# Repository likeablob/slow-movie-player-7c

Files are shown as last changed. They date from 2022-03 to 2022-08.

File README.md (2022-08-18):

<p align="center">
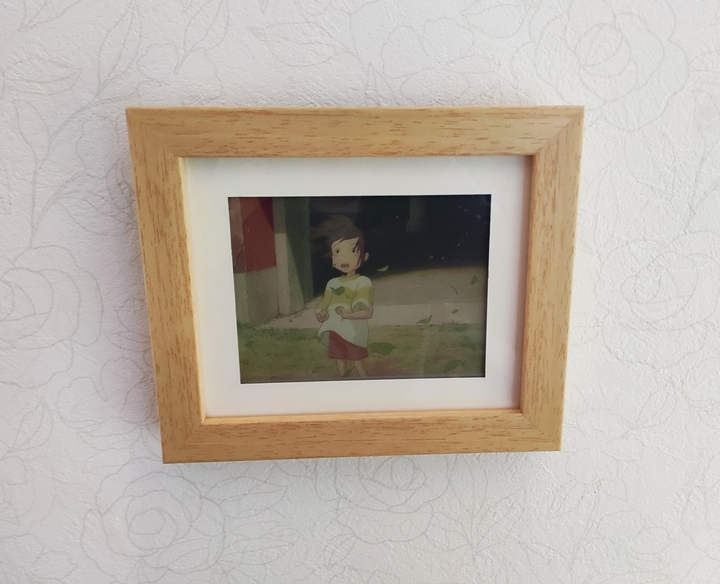
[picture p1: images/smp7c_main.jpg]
  
  <p align="center">
  <small>From "Spirited Away (2001)" © 2001 Studio Ghibli・NDDTM.</small>
  </p>
</p>

https://user-images.githubusercontent.com/46628917/185350349-dca5a5df-3bee-4c23-829b-23d41562c1f2.mp4

# slow-movie-player-7c



Yet another "Slow Movie Player" implementation with 7-color E-Paper module and ESP32.

Features:

- 7-color E-Paper
- microSD (MMC_SD) as the main storage
- Power management by the ESP32 ULP coprocessor
- Battery operated (12 uA @ Deep Sleep. Runs 1.2 years on a 2000 mAh battery.)

## Table of Contents

- [Background](#background)
- [Install](#install)
- [Usage](#usage)
- [Maintainers](#maintainers)
- [Contributing](#contributing)
- [License](#license)

## Background

A few years later from my previous EPD project [SHIHEN](https://github.com/likeablob/shihen), while being impressed on "Slow Movie" and forks ([[1]](https://hackaday.io/project/179122-slow-ish-movie-player), [[2]](https://github.com/TomWhitwell/SlowMovie)), I was wondering it would be fun if I could also have something bigger and more eye-catching than SHIHEN. One day I found a multi-color E-Paper module available and immediately made an impulse buy. At that time, in [Endless Endless Eight](https://github.com/likeablob/endless-endless-eight/) I had just started learning how powerful ESP32 ULP co-processor is, especially for battery-powered devices. So I decided to make a yet another variant of slow movie player by combining the two components.

The 7-color EPD module has notoriously long refresh time (>= 30 sec), however by delegating BUSY signal handlings to the ULP co-processor, the ESP32 module itself can be stay in Deep Sleep at most of the time.

Given the ESP32 module in the Deep Sleep mode only draws a dozen uA (Actually `12 uA` measured = `6 uA for the module` + `6 uA for peripherals`.), [theoretically the device can survive over a year](https://blc.vercel.app/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) under a 2000 mAh rated battery and 2 hours of wake interval.

## Install

### BOM

_WIP_

- ESP32 (ESP-WROOM-32)
- Waveshare ACeP 7-Color E-Paper Display Module (600x448 5.65inch)
- SMD microSD slot
- microSD card
- M2\*5 screws \* 4
- AAA batteries \* 3

### Wire components

See [./kicad](./kicad).

### Print spacers

See [./openscad](./openscad).

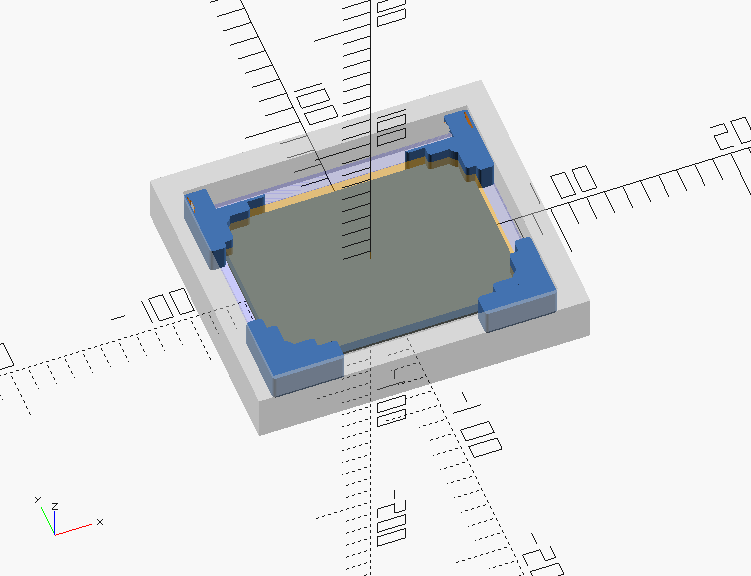
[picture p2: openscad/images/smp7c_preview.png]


### Build firmware

```sh
$ pio run || pio run # The very 1st run may fail due to ulptool-pio
$ pio run -t upload
```

## Usage

### Prepare video file

Your video file must get converted to a special format before being placed on the microSD.
Simply put `1. Dump video frames to a bunch of PNG images.` `2. Apply palette to the images.` `3. Concat the images into a single file.`

You have several options as follows. After obtaining `index.bin` and `images.bin`, place them onto the root of your FAT32-formatted microSD.

#### Option A: With Docker

```sh
$ cd converter
$ cp path/to/your_vid_file .
$ docker-compose run --rm converter your_vid_file
```

#### Option B: With .sh

- Note that you have to install ffmpeg, ImageMagick, node(v16) beforehand.

```sh
$ cd converter
$ ./convert.sh path/to/your_vid_file
```

#### Option C: By your hand

1. Dump video frames into .png files.

```sh
$ cd converter
$ mkdir -p vid

# -r 1/2 == 0.5 FPS
$ ffmpeg -i path/to/your_vid_file -r 1/2 -vf scale=-1:448,crop=600:448 vid/vid_%06d.png
```

As you may have noticed, you can use any kind of image sources here not only usual video files.

2. Reduce colors with the following 7-color palette.  
   

```sh
$ mogrify -monitor -dither FloydSteinberg -remap epaper_7c_palette.png vid/*
```

3. Generate `index.bin` and `images.bin`.

```sh
$ npm ci
$ node generate-index-bin.js vid/
```

### How it works

_WIP_

## Maintainers

[@likeablob](https://github.com/likeablob)

## Contributing

PRs accepted.

Small note: If editing the README, please conform to the [standard-readme](https://github.com/RichardLitt/standard-readme) specification.

## License

MIT

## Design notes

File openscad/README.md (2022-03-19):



# SMP7C parts

```sh
# Ensure you have submodules
$ git submodule update --init

# Convert *.scad to *.stl
$ make stls

# Generate thumbnails
$ make images
```

All the `*.stl` files are available under [`./stl`](./stl).

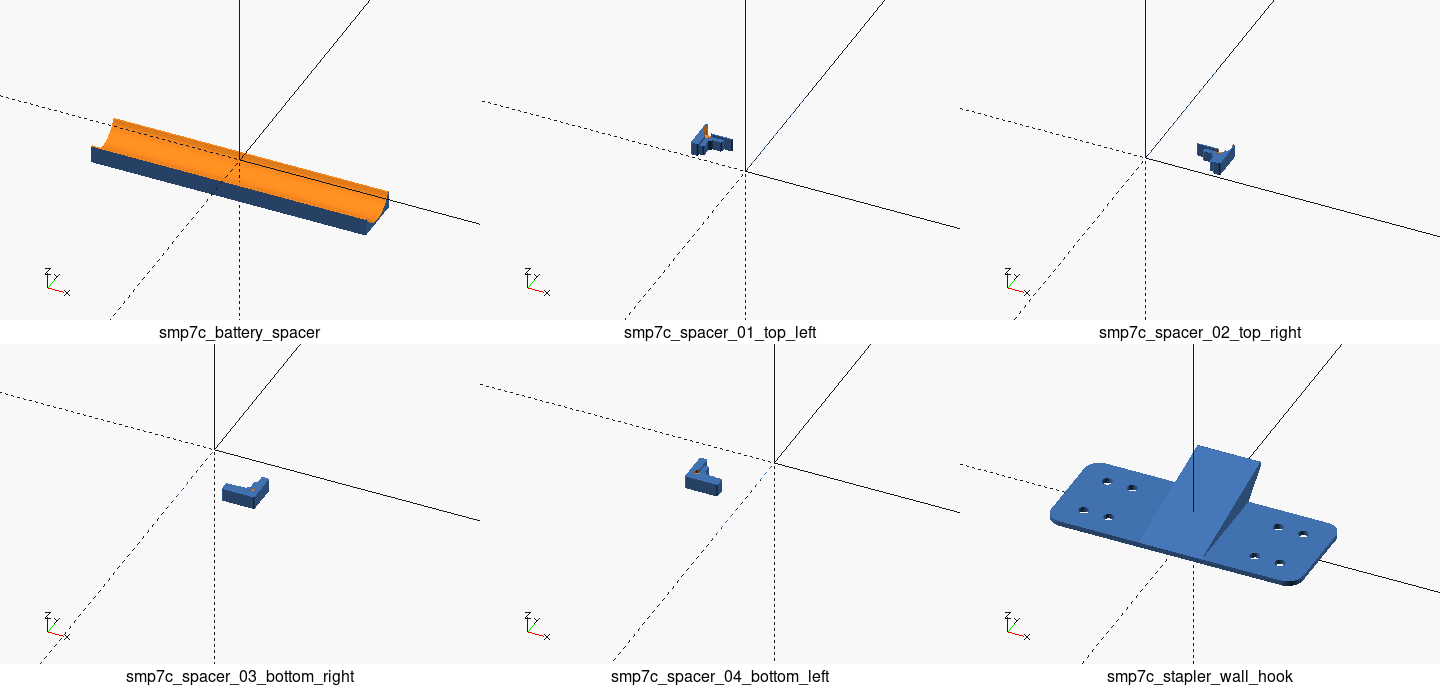
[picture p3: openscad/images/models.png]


## Recommended print configuration

- PLA
- Layer: 0.2 mm

## Parameters

See [`_preview_picture_frame_parameters.scad`](./_preview_picture_frame_parameters.scad) for the details.

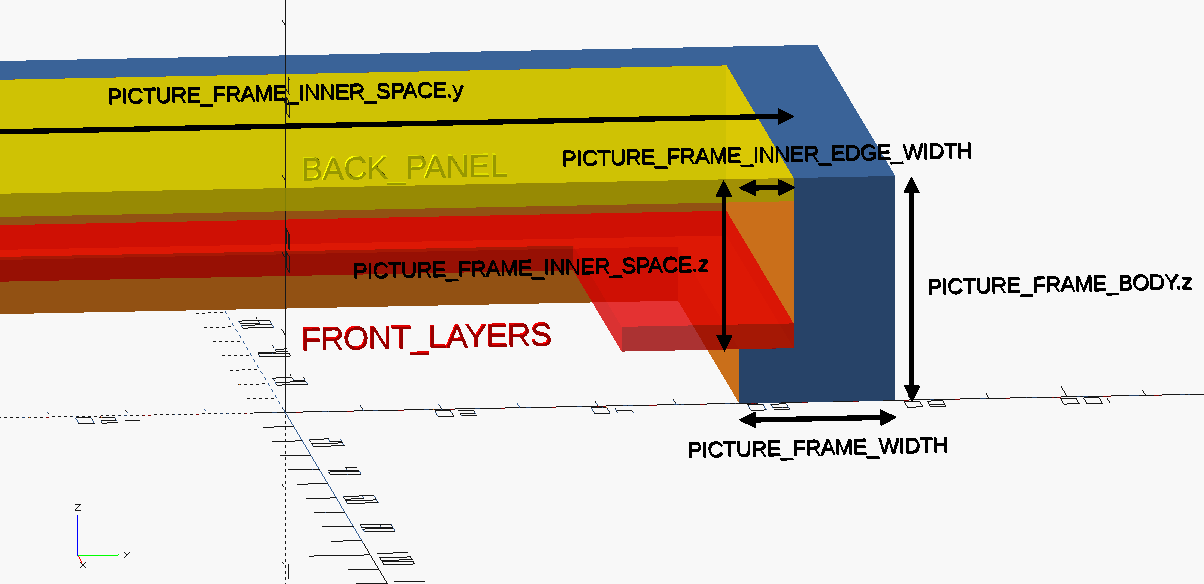
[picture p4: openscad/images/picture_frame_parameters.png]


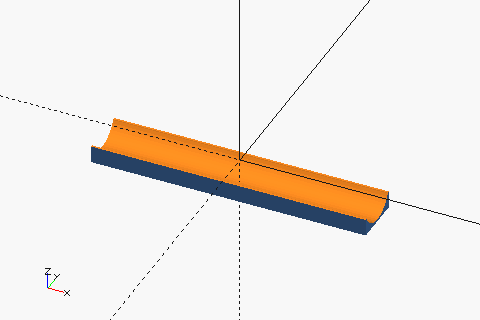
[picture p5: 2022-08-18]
openscad/images/smp7c_battery_spacer.png

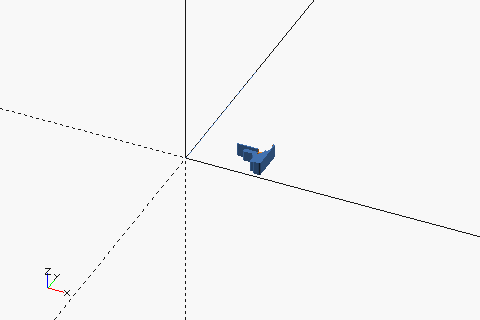
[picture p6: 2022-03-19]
openscad/images/smp7c_spacer_02_top_right.png

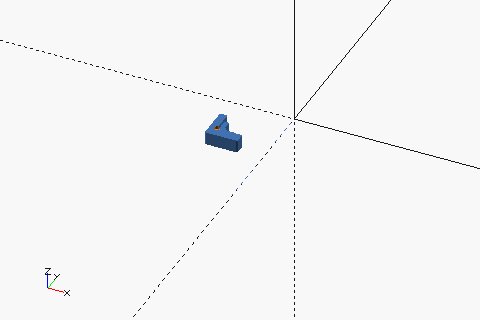
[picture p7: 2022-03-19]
openscad/images/smp7c_spacer_04_bottom_left.png

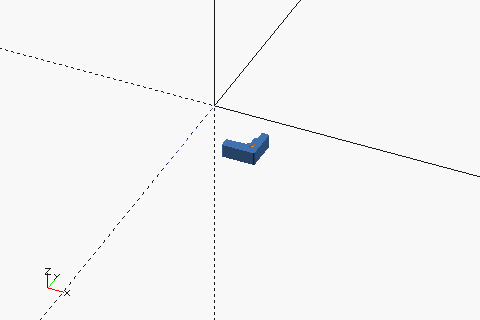
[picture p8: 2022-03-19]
openscad/images/smp7c_spacer_03_bottom_right.png

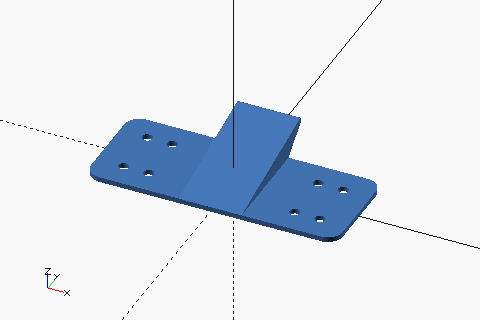
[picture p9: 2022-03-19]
openscad/images/smp7c_stapler_wall_hook.png

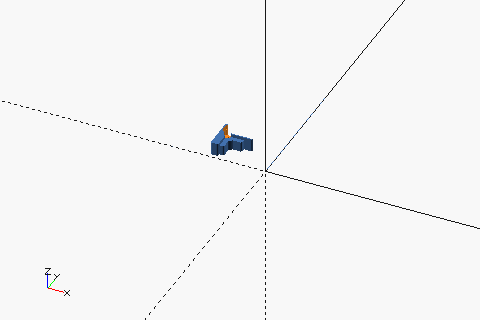
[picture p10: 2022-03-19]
openscad/images/smp7c_spacer_01_top_left.png

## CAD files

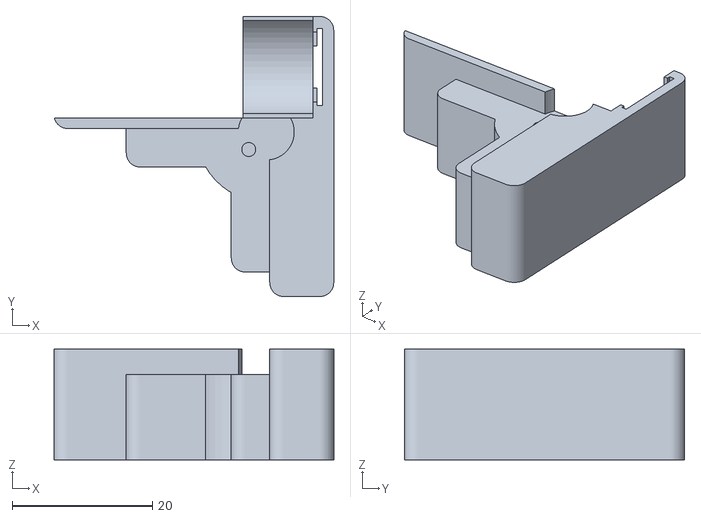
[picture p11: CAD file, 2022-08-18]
openscad/stl/smp7c_spacer_02_top_right.stl
39.9 x 40.0 x 15.8

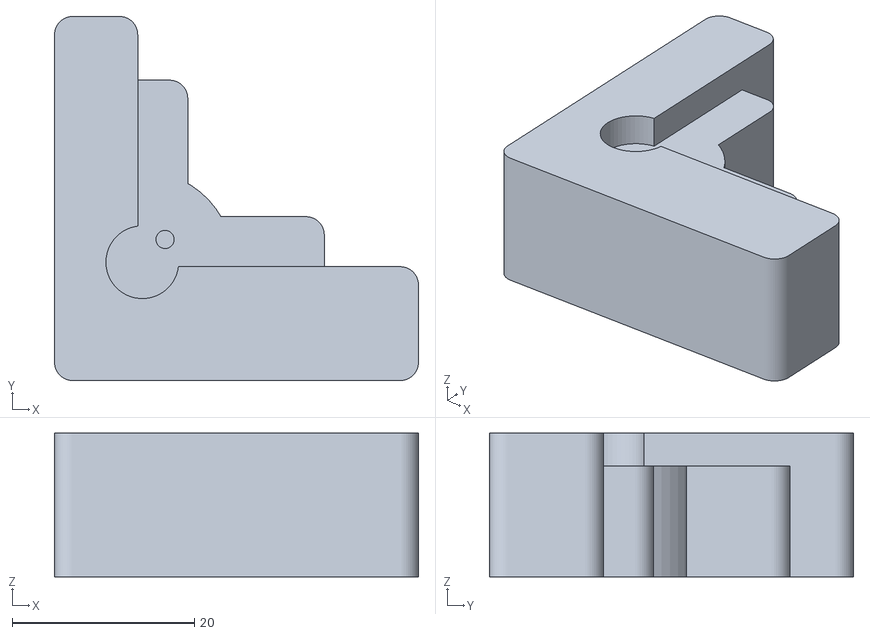
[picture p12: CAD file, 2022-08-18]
openscad/stl/smp7c_spacer_04_bottom_left.stl
40.0 x 40.0 x 15.8

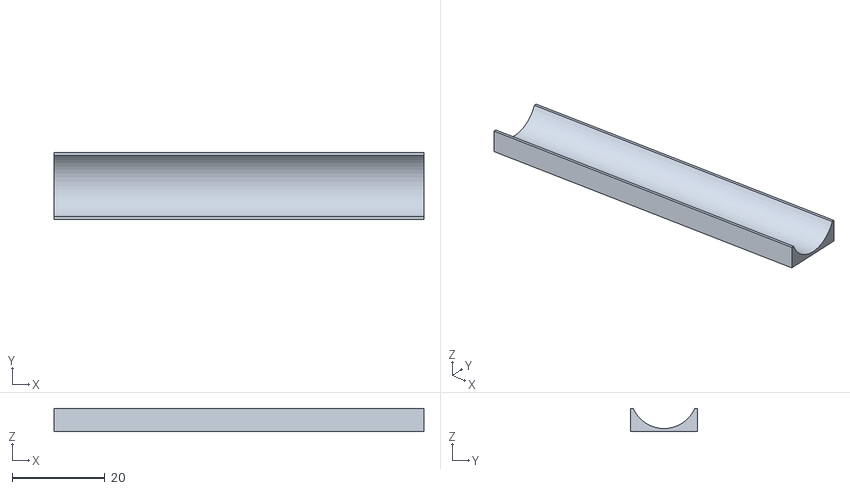
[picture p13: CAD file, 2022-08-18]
openscad/stl/smp7c_battery_spacer.stl
80.0 x 14.5 x 5.00

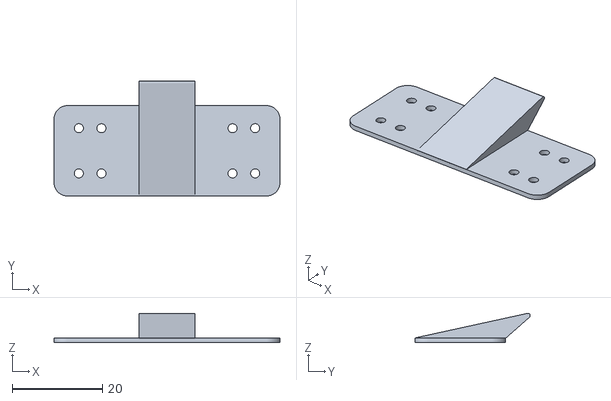
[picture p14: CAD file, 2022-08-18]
openscad/stl/smp7c_stapler_wall_hook.stl
50.0 x 25.5 x 6.50

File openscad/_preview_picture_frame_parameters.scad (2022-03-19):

include <modules/epd_565in_acep.scad>
include <modules/picture_frame.scad>
include <modules/smp7c_spacer.scad>
include <modules/annotation.scad>

$fn=50;

module cut_half_yz() {
  intersection(){
    children();

    translate([-1000/2, 0, 0])
    cube(size=[1000, 1000, 1000], center=true);
  }
}

// Models
cut_half_yz()
picture_frame_body();

translate([0.01, 0, 0])
color("red", 0.8)
cut_half_yz()
picture_frame_front_layers();

translate([0.02, 0, 0])
color("yellow", 0.8)
cut_half_yz()
picture_frame_back_panel();

// Annotations
// on YZ plane
rotate([90, 0, 90]){
  color("black")
  translate([PICTURE_FRAME_BODY.y/2 - PICTURE_FRAME_WIDTH/2, 0, 1]){
    translate([0, -2, 0])
    arrow(length=PICTURE_FRAME_WIDTH ,label="PICTURE_FRAME_WIDTH", label_pos_reverse=false);

    translate([PICTURE_FRAME_WIDTH/2 + 2, PICTURE_FRAME_BODY.z/2, 0])
    arrow(length=PICTURE_FRAME_BODY.z, vertical=true, label="PICTURE_FRAME_BODY.z", label_pos_reverse=false);

    translate([-PICTURE_FRAME_WIDTH/2 + PICTURE_FRAME_INNER_EDGE_WIDTH/2, PICTURE_FRAME_BODY.z - 1, 0])
    arrow(length=PICTURE_FRAME_INNER_EDGE_WIDTH, label="PICTURE_FRAME_INNER_EDGE_WIDTH", label_pos_reverse=true);

    translate([-PICTURE_FRAME_WIDTH/2 - 2, PICTURE_FRAME_INNER_SPACE.z/2 + PICTURE_FRAME_WINDOW_Z, 0])
    arrow(length=PICTURE_FRAME_INNER_SPACE.z, vertical=true, label="PICTURE_FRAME_INNER_SPACE.z", label_pos_reverse=true);
  }

  translate([2, PICTURE_FRAME_BODY.z + 1, 0])
  color("yellow")
  text("BACK_PANEL", size=3);

  translate([2, PICTURE_FRAME_WINDOW_Z + 1, 0])
  color("red")
  text("FRONT_LAYERS", size=3);

  color("black")
  translate([0, PICTURE_FRAME_BODY.z + 8, 0])
  arrow(length=PICTURE_FRAME_INNER_SPACE.y, vertical=false, label="PICTURE_FRAME_INNER_SPACE.y", label_pos_reverse=true);
}

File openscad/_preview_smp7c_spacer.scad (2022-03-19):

include <modules/epd_565in_acep.scad>
include <modules/picture_frame.scad>
include <modules/smp7c_spacer.scad>

$fn=50;


%
translate_to_picture_frame_available_inner_space_zplane(as_origin_plane=true){
  picture_frame_body();
  picture_frame_front_layers();
  // picture_frame_back_panel();
}


translate([0, 0, EPD_MODULE_EPD.z])
translate_to_epd_visible_area_center(as_center=true)
epd_module_body();

smp7c_spacer_body(with_battery_space=true);

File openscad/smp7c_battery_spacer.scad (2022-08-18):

include <modules/picture_frame.scad>

$fn=50;


module smp7c_battery_spacer_body() {
  difference(){
    cube(size=[80, 14.5, PICTURE_FRAME_INNER_SPACE_AVAILABLE_Z], center=true);

    // Space for batteries
    rotate([0, 90, 0])
    cylinder(d=14.5, h=80 + 1, center=true);

    // Slice it
    translate([0, 0, 5])
    cube(size=[80 + 1, 14.5 + 1, PICTURE_FRAME_INNER_SPACE_AVAILABLE_Z], center=true);
  }
}

smp7c_battery_spacer_body();

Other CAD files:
openscad/stl/smp7c_spacer_01_top_left.stl
openscad/stl/smp7c_spacer_03_bottom_right.stl
openscad/smp7c_spacer_01_top_left.scad
openscad/modules/annotation.scad
openscad/modules/epd_565in_acep.scad
openscad/modules/picture_frame.scad
openscad/modules/smp7c_spacer.scad
openscad/smp7c_spacer_02_top_right.scad
openscad/smp7c_spacer_03_bottom_right.scad
openscad/smp7c_spacer_04_bottom_left.scad
openscad/smp7c_stapler_wall_hook.scad

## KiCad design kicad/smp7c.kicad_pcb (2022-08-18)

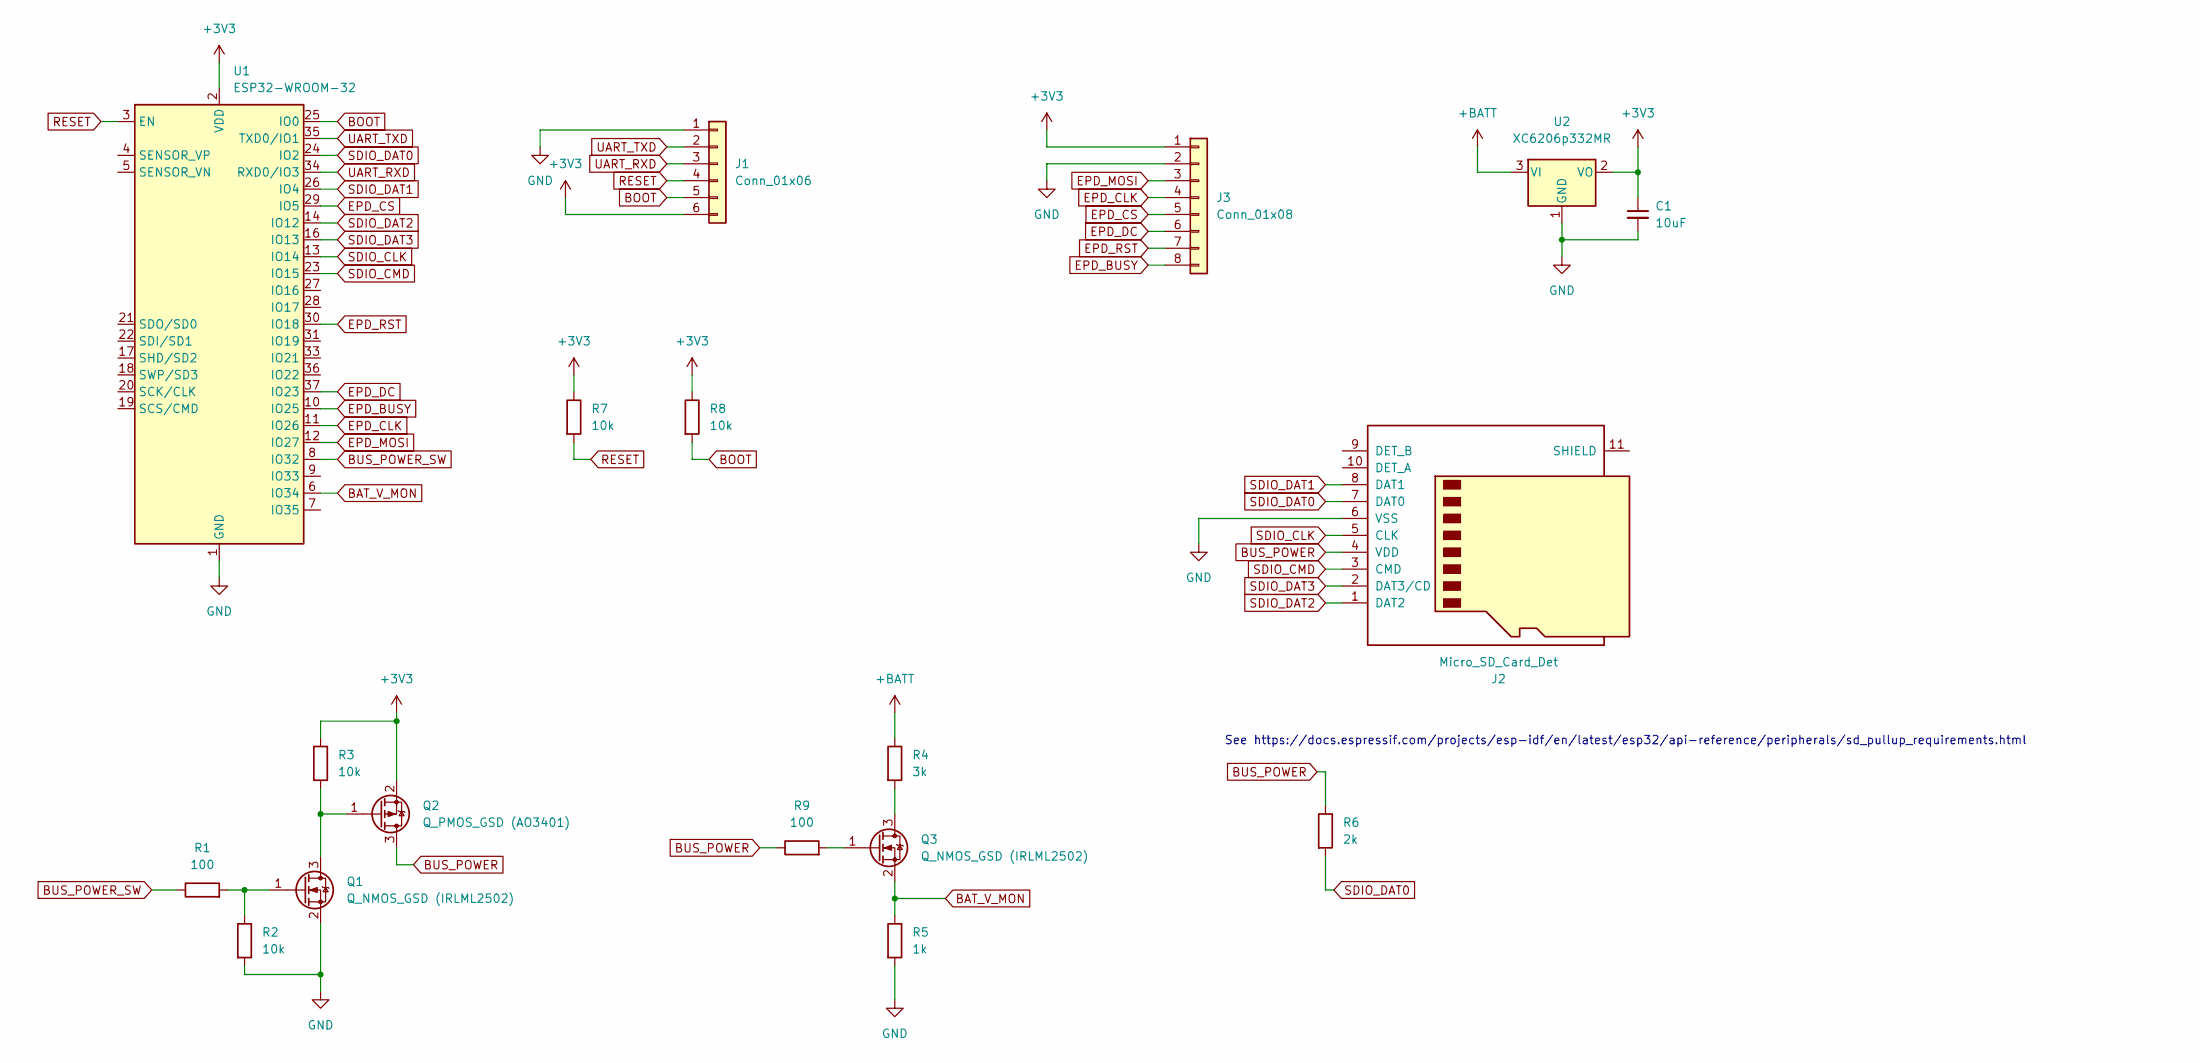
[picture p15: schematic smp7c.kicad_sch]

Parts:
C1: 10uF; C_1206_3216Metric
J1: Conn_01x06; PinSocket_1x06_P2.54mm_Vertical
J2: Micro_SD_Card_Det; microSD_HC_Hirose_DM3BT-DSF-PEJS
J3: Conn_01x08; PinSocket_1x08_P2.54mm_Vertical
Q1, Q3: Q_NMOS_GSD (IRLML2502); SOT-23
Q2: Q_PMOS_GSD (AO3401); SOT-23
R1, R9: 100; R_0603_1608Metric
R2, R3, R7, R8: 10k; R_0603_1608Metric
R4: 3k; R_0603_1608Metric
R5: 1k; R_0603_1608Metric
R6: 2k; R_0603_1608Metric
U1: ESP32-WROOM-32
U2: XC6206p332MR; SOT-23

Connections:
+3V3: C1.1, J1.6, J3.1, Q2.2 (S), R3.1, R7.1, R8.1, U1.2 (VDD), U2.2 (VO)
+BATT: R4.1, U2.3 (VI)
BAT_V_MON: Q3.2 (S), R5.1, U1.6 (IO34)
BOOT: J1.5, R8.2, U1.25 (IO0)
BUS_POWER: J2.4 (VDD), Q2.3 (D), R6.1, R9.1
BUS_POWER_SW: R1.1, U1.8 (IO32)
EPD_BUSY: J3.8, U1.10 (IO25)
EPD_CLK: J3.4, U1.11 (IO26)
EPD_CS: J3.5, U1.29 (IO5)
EPD_DC: J3.6, U1.37 (IO23)
EPD_MOSI: J3.3, U1.12 (IO27)
EPD_RST: J3.7, U1.30 (IO18)
GND: C1.2, J1.1, J2.6 (VSS), J3.2, Q1.2 (S), R2.2, R5.2, U1.1 (GND), U1.15 (GND), U1.38 (GND), U1.39 (GND), U2.1 (GND)
unnamed: Q1.1 (G), R1.2, R2.1
unnamed: Q1.3 (D), Q2.1 (G), R3.2
unnamed: Q3.1 (G), R9.2
unnamed: Q3.3 (D), R4.2
RESET: J1.4, R7.2, U1.3 (EN)
SDIO_CLK: J2.5 (CLK), U1.13 (IO14)
SDIO_CMD: J2.3 (CMD), U1.23 (IO15)
SDIO_DAT0: J2.7 (DAT0), R6.2, U1.24 (IO2)
SDIO_DAT1: J2.8 (DAT1), U1.26 (IO4)
SDIO_DAT2: J2.1 (DAT2), U1.14 (IO12)
SDIO_DAT3: J2.2 (DAT3/CD), U1.16 (IO13)
UART_RXD: J1.3, U1.34 (RXD0/IO3)
UART_TXD: J1.2, U1.35 (TXD0/IO1)

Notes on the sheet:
See https://docs.espressif.com/projects/esp-idf/en/latest/esp32/api-reference/peripherals/sd_pullup_requirements.html

Board: 2 copper layers, 18 parts (1 on the bottom side), 26 nets, no tracks yet.

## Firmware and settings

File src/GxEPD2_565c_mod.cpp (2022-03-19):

// Display Library for SPI e-paper panels from Dalian Good Display and boards
// from Waveshare. Requires HW SPI and Adafruit_GFX. Caution: the e-paper panels
// require 3.3V supply AND data lines!
//
// based on Demo Example from Good Display:
// http://www.e-paper-display.com/download_detail/downloadsId=808.html
// Panel: 5.65inch ACeP 7-Color E-Paper :
// https://www.waveshare.com/product/displays/e-paper/5.65inch-e-paper-module-f.htm
// Controller: unknonw
// initcode extracted from Waveshare library file epd5in65f.cpp available here:
// https://www.waveshare.com/wiki/5.65inch_e-Paper_Module_(F)
//
// Author: Jean-Marc Zingg
//
// Version: see library.properties
//
// Library: https://github.com/ZinggJM/GxEPD2
//
// Modified by likeablob for SMP7C. Removed busy wait handling.

#include "GxEPD2_565c_mod.h"

GxEPD2_565c::GxEPD2_565c(int16_t cs, int16_t dc, int16_t rst, int16_t busy)
    : GxEPD2_EPD(cs, dc, rst, busy, LOW, 25000000, WIDTH, HEIGHT, panel,
                 hasColor, hasPartialUpdate, hasFastPartialUpdate) {
    _paged = false;
}

void GxEPD2_565c::clearScreen(uint8_t value) { clearScreen(value, 0xFF); }

void GxEPD2_565c::clearScreen(uint8_t black_value, uint8_t color_value) {
    writeScreenBuffer(black_value, color_value);
    _Update_Full();
}

void GxEPD2_565c::writeScreenBuffer(uint8_t value) {
    writeScreenBuffer(value, 0xFF);
}

void GxEPD2_565c::writeScreenBuffer(uint8_t black_value, uint8_t color_value) {
    _initial_write = false; // initial full screen buffer clean done
    _Init_Full();
    _writeCommand(0x10);
    _startTransfer();
    for(uint32_t i = 0; i < uint32_t(WIDTH) * uint32_t(HEIGHT) / 2; i++) {
        //_transfer(0x11);
        _transfer(0xFF == black_value ? 0x11 : black_value);
    }
    _endTransfer();
}

void GxEPD2_565c::writeImage(const uint8_t bitmap[], int16_t x, int16_t y,
                             int16_t w, int16_t h, bool invert, bool mirror_y,
                             bool pgm) {
    // Serial.print("writeImage("); Serial.print(x); Serial.print(", ");
    // Serial.print(y); Serial.print(", "); Serial.print(w); Serial.print(", ");
    // Serial.print(h); Serial.println(")");
    delay(1); // yield() to avoid WDT on ESP8266 and ESP32
    if(_paged && (x == 0) && (w == int16_t(WIDTH)) && (h < int16_t(HEIGHT))) {
        // Serial.println("paged");
        _startTransfer();
        for(uint32_t i = 0; i < uint32_t(WIDTH) * uint32_t(h) / 8; i++) {
            uint8_t data = bitmap[i];
            for(int16_t k = 0; k < 4; k++) {
                uint8_t data2 =
                    (data & 0x80 ? 0x10 : 0x00) | (data & 0x40 ? 0x01 : 0x00);
                data <<= 2;
                _transfer(data2);
            }
        }
        _endTransfer();
        if(y + h == HEIGHT) // last page
        {
            // Serial.println("paged ended");
            _paged = false;
        }
    } else {
        _paged = false;
        int16_t wb = (w + 7) / 8; // width bytes, bitmaps are padded
        x -= x % 8;               // byte boundary
        w = wb * 8;               // byte boundary
        if((w <= 0) || (h <= 0))
            return;
        _Init_Full();
        _writeCommand(0x10);
        _startTransfer();
        for(int16_t i = 0; i < int16_t(HEIGHT); i++) {
            for(int16_t j = 0; j < int16_t(WIDTH); j += 8) {
                uint8_t data = 0xFF;
                if((j >= x) && (j <= x + w) && (i >= y) && (i < y + h)) {
                    uint32_t idx =
                        mirror_y
                            ? (j - x) / 8 + uint32_t((h - 1 - (i - y))) * wb
                            : (j - x) / 8 + uint32_t(i - y) * wb;
                    if(pgm) {
#if defined(__AVR) || defined(ESP8266) || defined(ESP32)
                        data = pgm_read_byte(&bitmap[idx]);
#else
                        data = bitmap[idx];
#endif
                    } else {
                        data = bitmap[idx];
                    }
                    if(invert)
                        data = ~data;
                }
                for(int16_t k = 0; k < 4; k++) {
                    uint8_t data2 = (data & 0x80 ? 0x10 : 0x00) |
                                    (data & 0x40 ? 0x01 : 0x00);
                    data <<= 2;
                    _transfer(data2);
                }
            }
        }
        _endTransfer();
    }
    delay(1); // yield() to avoid WDT on ESP8266 and ESP32
}
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

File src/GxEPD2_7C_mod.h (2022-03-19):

// Display Library for SPI e-paper panels from Dalian Good Display and boards
// from Waveshare. Requires HW SPI and Adafruit_GFX. Caution: these e-papers
// require 3.3V supply AND data lines!
//
// based on Demo Example from Good Display:
// http://www.e-paper-display.com/download_list/downloadcategoryid=34&isMode=false.html
//
// Author: Jean-Marc Zingg
//
// Version: see library.properties
//
// Library: https://github.com/ZinggJM/GxEPD2
//
// Modified by likeablob for SMP7C. To have single paged operation.

#ifndef _GxEPD2_7C_H_
#define _GxEPD2_7C_H_
// uncomment next line to use class GFX of library GFX_Root instead of
// Adafruit_GFX
//#include <GFX.h>

#ifndef ENABLE_GxEPD2_GFX
// default is off
#define ENABLE_GxEPD2_GFX 0
#endif

#if ENABLE_GxEPD2_GFX
#include "GxEPD2_GFX.h"
#define GxEPD2_GFX_BASE_CLASS GxEPD2_GFX
#elif defined(_GFX_H_)
#define GxEPD2_GFX_BASE_CLASS GFX
#else
#include <Adafruit_GFX.h>
#define GxEPD2_GFX_BASE_CLASS Adafruit_GFX
#endif

// Modify to have a pseudo page buffer which is actually splitted into two byte
// buffers. This is because ESP32 doesn't allow allocating 131 KiB(600 * 448 /
// 2) of a single contiguous buffer.
#define PIXEL_BUFFER_LEN ((GxEPD2_Type::WIDTH / 2) * page_height / 2)
#define PIXEL_BUFFER(i)                                                        \
    ((i) < PIXEL_BUFFER_LEN ? (_pixel_buffer_a[(i)])                           \
                            : (_pixel_buffer_b[(i)-PIXEL_BUFFER_LEN]))

// Hidden 8th color?
#define GxEPD_BEIGE 0x07

#include "GxEPD2_565c_mod.h"
#include "GxEPD2_EPD.h"

template <typename GxEPD2_Type, const uint16_t page_height>
class GxEPD2_7C : public GxEPD2_GFX_BASE_CLASS {
  public:
    GxEPD2_Type epd2;
#if ENABLE_GxEPD2_GFX
    GxEPD2_7C(GxEPD2_Type epd2_instance)
        : GxEPD2_GFX_BASE_CLASS(epd2, GxEPD2_Type::WIDTH, GxEPD2_Type::HEIGHT),
          epd2(epd2_instance)
#else
    GxEPD2_7C(GxEPD2_Type epd2_instance)
        : GxEPD2_GFX_BASE_CLASS(GxEPD2_Type::WIDTH, GxEPD2_Type::HEIGHT),
          epd2(epd2_instance)
#endif
    {
        _page_height = page_height;
        _pages = (HEIGHT / _page_height) + ((HEIGHT % _page_height) > 0);
        _mirror = false;
        _using_partial_mode = false;
        _current_page = 0;
        setFullWindow();
    }

    uint16_t pages() { return _pages; }

    uint16_t pageHeight() { return _page_height; }

    bool mirror(bool m) {
        _swap_(_mirror, m);
        return m;
    }

    void drawPixel(int16_t x, int16_t y, uint16_t color) {
        if((x < 0) || (x >= width()) || (y < 0) || (y >= height()))
            return;
        if(_mirror)
            x = width() - x - 1;
        // check rotation, move pixel around if necessary
        switch(getRotation()) {
        case 1:
            _swap_(x, y);
            x = WIDTH - x - 1;
            break;
        case 2:
            x = WIDTH - x - 1;
            y = HEIGHT - y - 1;
            break;
        case 3:
            _swap_(x, y);
            y = HEIGHT - y - 1;
            break;
        }
        // transpose partial window to 0,0
        x -= _pw_x;
        y -= _pw_y;
        // clip to (partial) window
        if((x < 0) || (x >= int16_t(_pw_w)) || (y < 0) || (y >= int16_t(_pw_h)))
            return;
        // adjust for current page
        y -= _current_page * _page_height;
        // check if in current page
        if((y < 0) || (y >= int16_t(_page_height)))
            return;
        uint32_t i = x / 2 + uint32_t(y) * (_pw_w / 2);
        uint8_t pv = color7(color);
        if(x & 1)
            // _pixel_buffer_a[i] = (_pixel_buffer_a[i] & 0xF0) | pv;
            PIXEL_BUFFER(i) = (PIXEL_BUFFER(i) & 0xF0) | pv;
        else
            // _pixel_buffer_a[i] = (_pixel_buffer_a[i] & 0x0F) | (pv << 4);
            PIXEL_BUFFER(i) = (PIXEL_BUFFER(i) & 0x0F) | (pv << 4);
    }

    void init(uint32_t serial_diag_bitrate = 0) // = 0 : disabled
    {
        epd2.init(serial_diag_bitrate);
        _using_partial_mode = false;
        _current_page = 0;
        _pixel_buffer_a = (uint8_t *)malloc(PIXEL_BUFFER_LEN);
        _pixel_buffer_b = (uint8_t *)malloc(PIXEL_BUFFER_LEN);
        setFullWindow();
    }

    // init method with additional parameters:
    // initial false for re-init after processor deep sleep wake up, if display
    // power supply was kept only relevant for b/w displays with fast partial
    // update reset_duration = 20 is default; a value of 2 may help with
    // "clever" reset circuit of newer boards from Waveshare pulldown_rst_mode
    // true for alternate RST handling to avoid feeding 5V through RST pin
    void init(uint32_t serial_diag_bitrate, bool initial,
              uint16_t reset_duration = 20, bool pulldown_rst_mode = false) {
        epd2.init(serial_diag_bitrate, initial, reset_duration,
                  pulldown_rst_mode);
        _using_partial_mode = false;
        _current_page = 0;
        setFullWindow();
    }

    // init method with additional parameters:
    // SPIClass& spi: either SPI or alternate HW SPI channel
    // SPISettings spi_settings: e.g. for higher SPI speed selection
    void init(uint32_t serial_diag_bitrate, bool initial,
              uint16_t reset_duration, bool pulldown_rst_mode, SPIClass &spi,
              SPISettings spi_settings) {
        epd2.selectSPI(spi, spi_settings);
        epd2.init(serial_diag_bitrate, initial, reset_duration,
                  pulldown_rst_mode);
        _using_partial_mode = false;
        _current_page = 0;
        setFullWindow();
    }

    void fillScreen(uint16_t color) {
        uint8_t pv = color7(color);
        uint8_t pv2 = pv | pv << 4;
        for(uint32_t x = 0; x < PIXEL_BUFFER_LEN; x++) {
            _pixel_buffer_a[x] = pv2;
        }
        for(uint32_t x = 0; x < PIXEL_BUFFER_LEN; x++) {
            _pixel_buffer_b[x] = pv2;
        }
    }

    // display buffer content to screen, useful for full screen buffer
    void display(bool partial_update_mode = false) {
        epd2.writeNative(_pixel_buffer_a, 0, 0, 0, WIDTH, _page_height / 2);
        epd2.writeNative(_pixel_buffer_b, 0, 0, _page_height / 2, WIDTH,
                         _page_height / 2);
        epd2.refresh(partial_update_mode);
        if(!partial_update_mode)
            epd2.powerOff();
    }
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

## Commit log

2022-08-18 Add battery_spacer for fixing batteries properly
    - Rebuild stls
    [smp7c_battery_spacer.scad, smp7c_battery_spacer.stl, smp7c_spacer.scad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]
2022-08-18 Implement battery voltage monitoring feature
    - Update schematic to have voltage divider for monitoring
    - Update firmware to monitor voltage and show low voltage notification
    [smp7c.kicad_pcb, smp7c.kicad_sch]
